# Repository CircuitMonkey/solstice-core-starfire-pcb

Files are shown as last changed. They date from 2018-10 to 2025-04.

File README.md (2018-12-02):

# solstice-core-starfire-pcb
Solstice Design System —  *Starfire* Core —  Eagle PCB

PCB files for the **Circuit Monkey** *StarFire*  **Solstice Core** *Module*

Format is EagleCAD 9.x schematic and board layout

*StarFire* is one of the first *Solstice Core* modules.

For more details, check out the product page at

  * https://www.circuitmonkey.com/product/0701   ( [404 - not found] this link is not yet active)

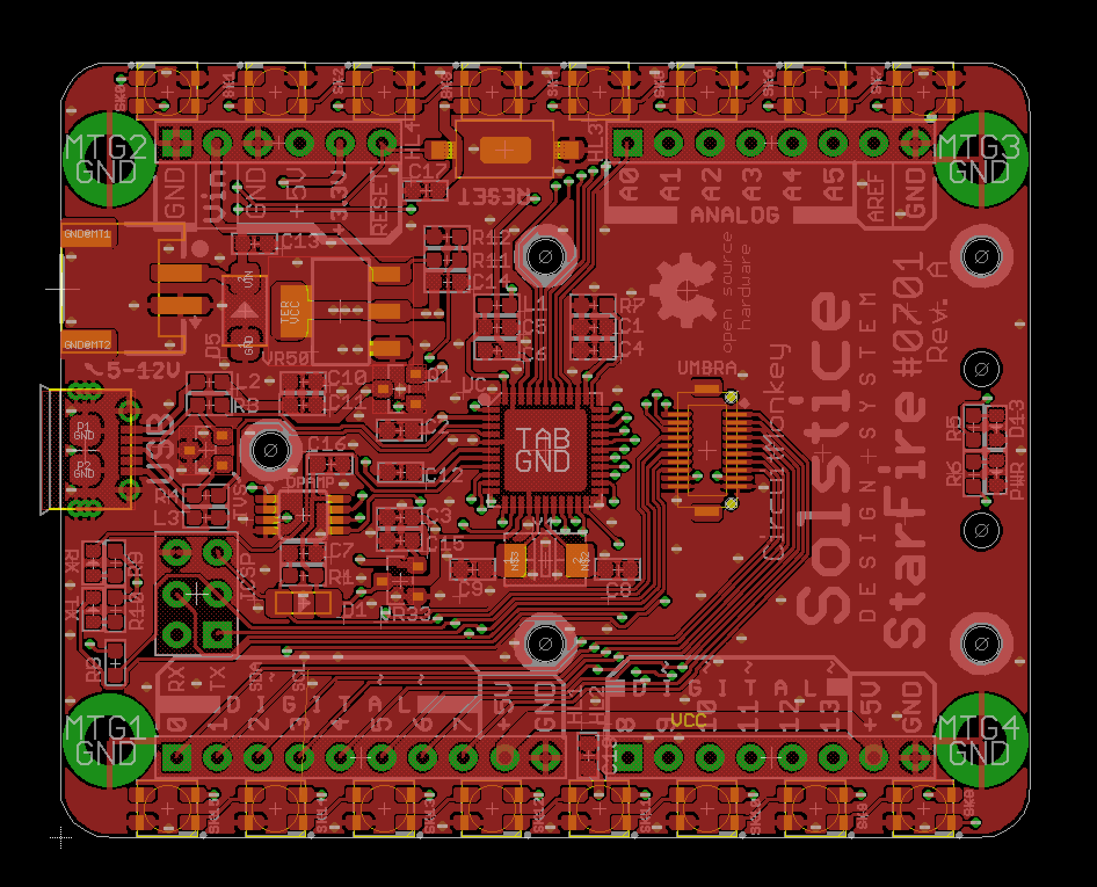
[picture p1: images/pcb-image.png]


### Revision Notes
* Rev. 0 - Initial board design.  This revision was made for evaluation and only
one unit ever made.

* Rev. A - First revision meant for human consumption.
  * Swapped Vin and GND pins on HaLo connector.   Vin was dangerously close to GND mounting hole.
  * Changed WS2812B (5x5mm) LEDs to smaller SK6812(3.5x3.5mm LEDs)
  * SK6812 LED chain is driven by SCK pin.  Was MISO pin on Rev.0 and pattern would scramble when ISP programming the board.
  * Reset switch changed to slightly larger type.
  * Mounting holes on corners changed from 2mm pan head-style to 3mm socket head type.  2mm hardware is harder to source.
  * Added Umbra connector.  A Umbra is 20-pin micro-shield that is approx. 1x1 inch and can mount under the regular shield(HaLo).
  * Added Umbra hardware mounting points throughout PCB.
  * Added mounting holes to support light pipe option at the PWR and D13 LEDs.

* Rev. B - Production version.
  * Added EN_PIXELS solder jumper on bottom of PCB to allow disabling of built-in RGB LEDs.
  * Added test points at bottom of PCB to allow externally extending the 16 on-board LEDs.
  * Added 330ohm serial resistor to external pixel output.
  * USB connector footprint issue addressed.  Footprint was correct, Seeed part number was incorrect.

## Designed by Circuit Monkey in Las Vegas, Nevada, USA
Creative Commons Attribution, Share-Alike license, check license.txt for more information. Derivative of "Arduino Leonardo Reference design" (http://www.arduino.cc/en/Main/ArduinoBoardLeonardo)

All text above must be included in any redistribution

## Gallery
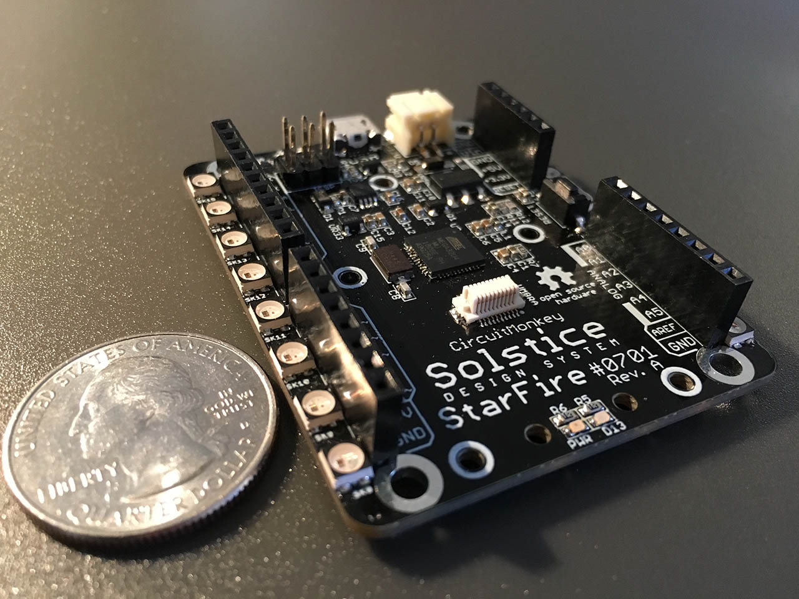
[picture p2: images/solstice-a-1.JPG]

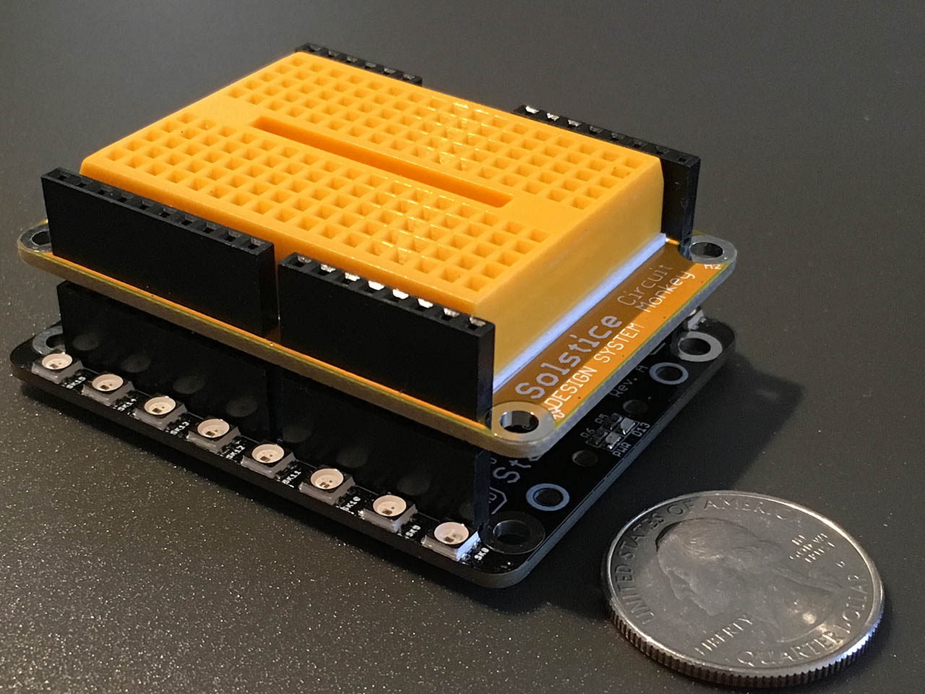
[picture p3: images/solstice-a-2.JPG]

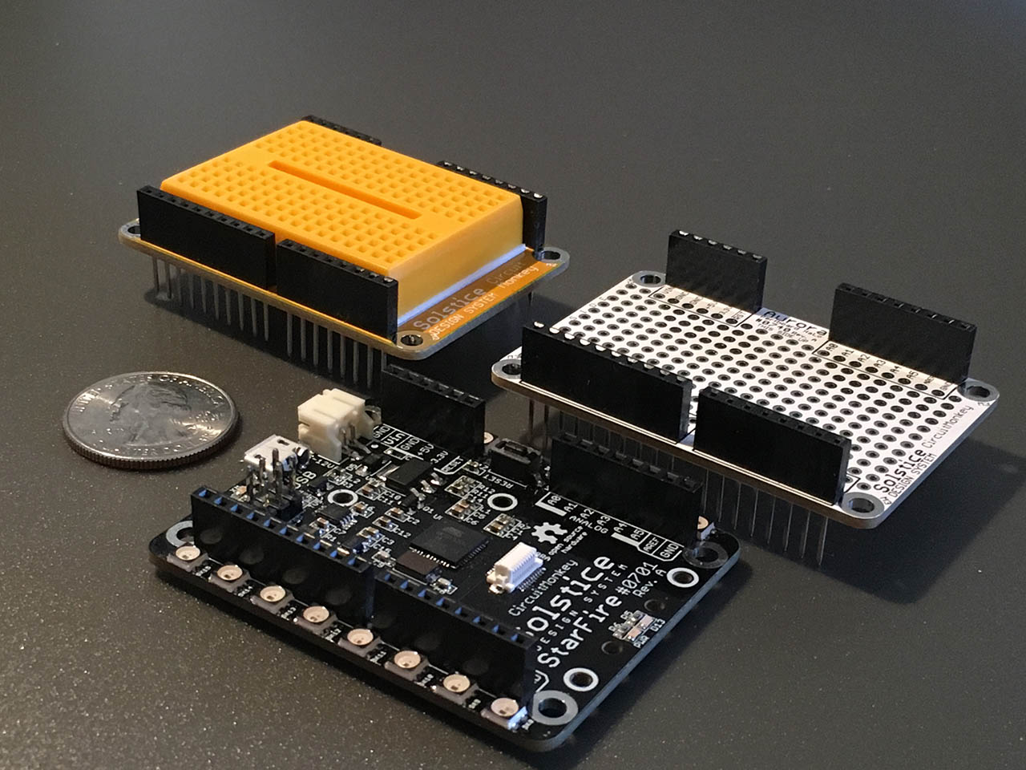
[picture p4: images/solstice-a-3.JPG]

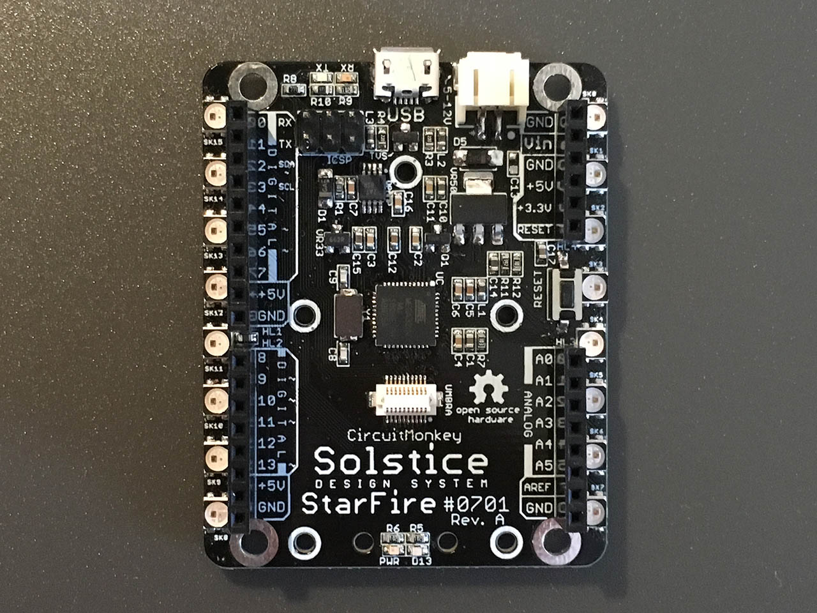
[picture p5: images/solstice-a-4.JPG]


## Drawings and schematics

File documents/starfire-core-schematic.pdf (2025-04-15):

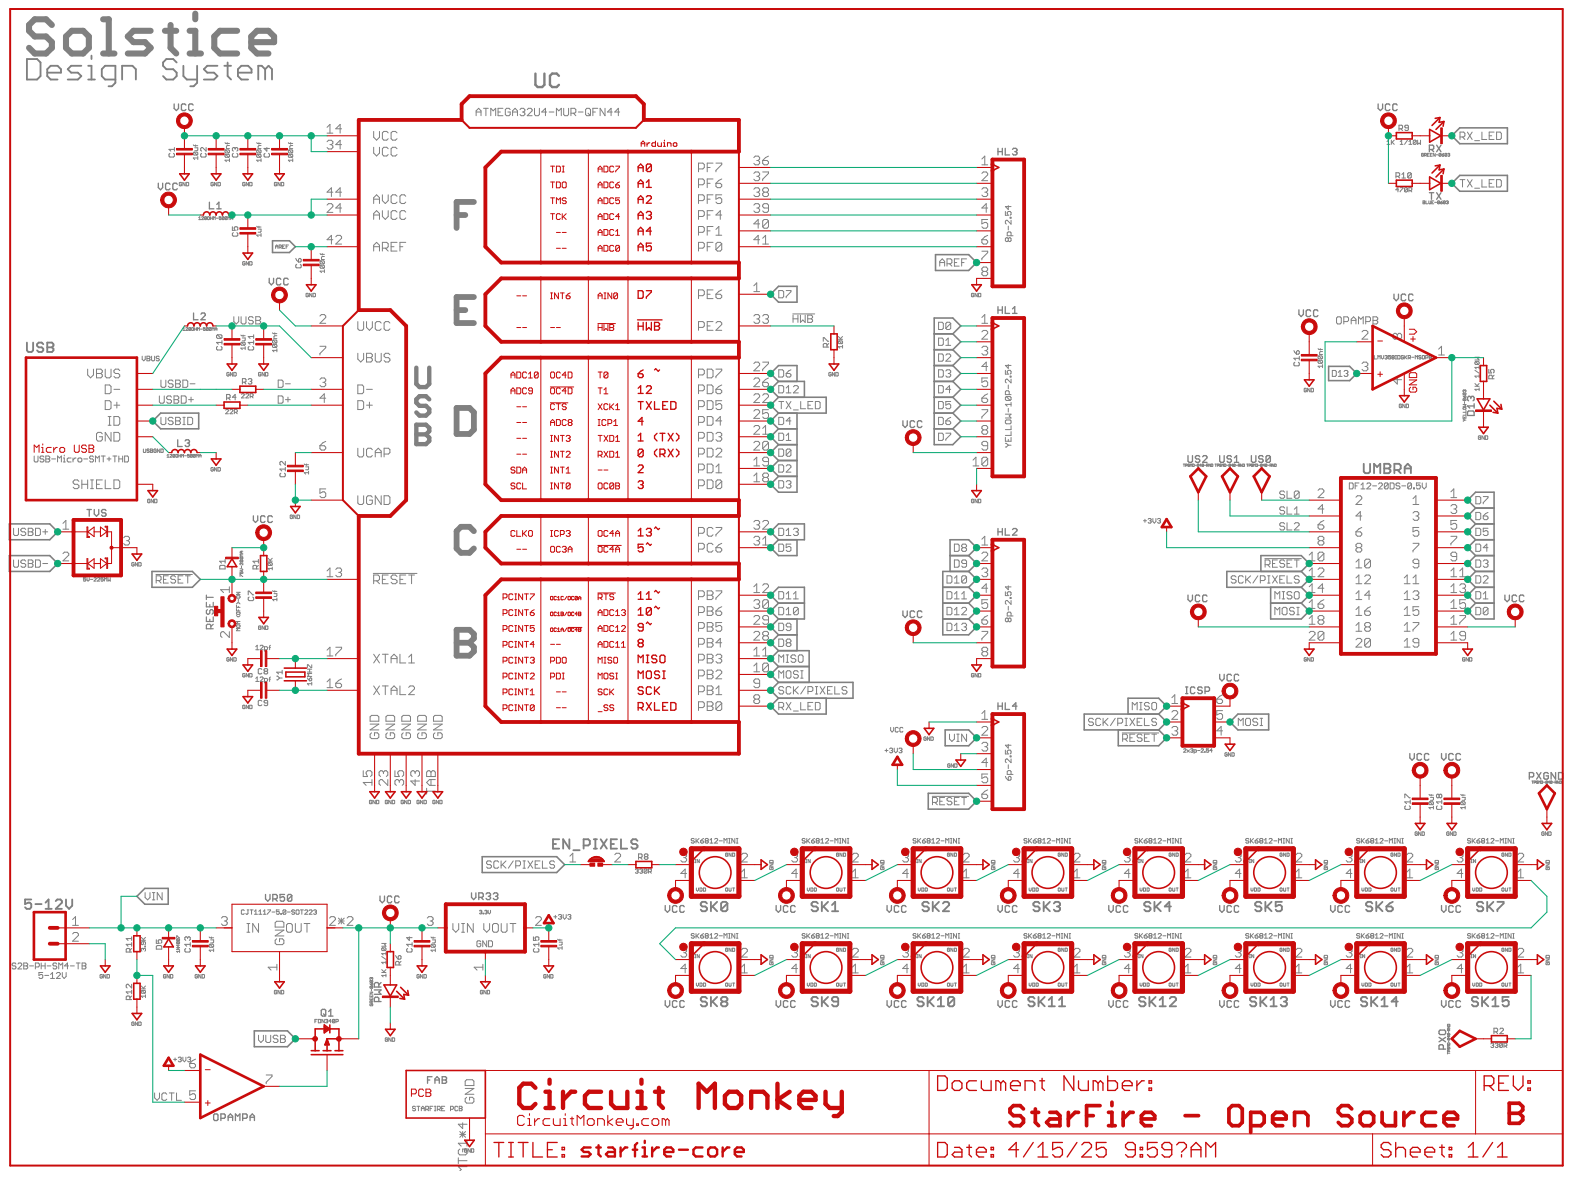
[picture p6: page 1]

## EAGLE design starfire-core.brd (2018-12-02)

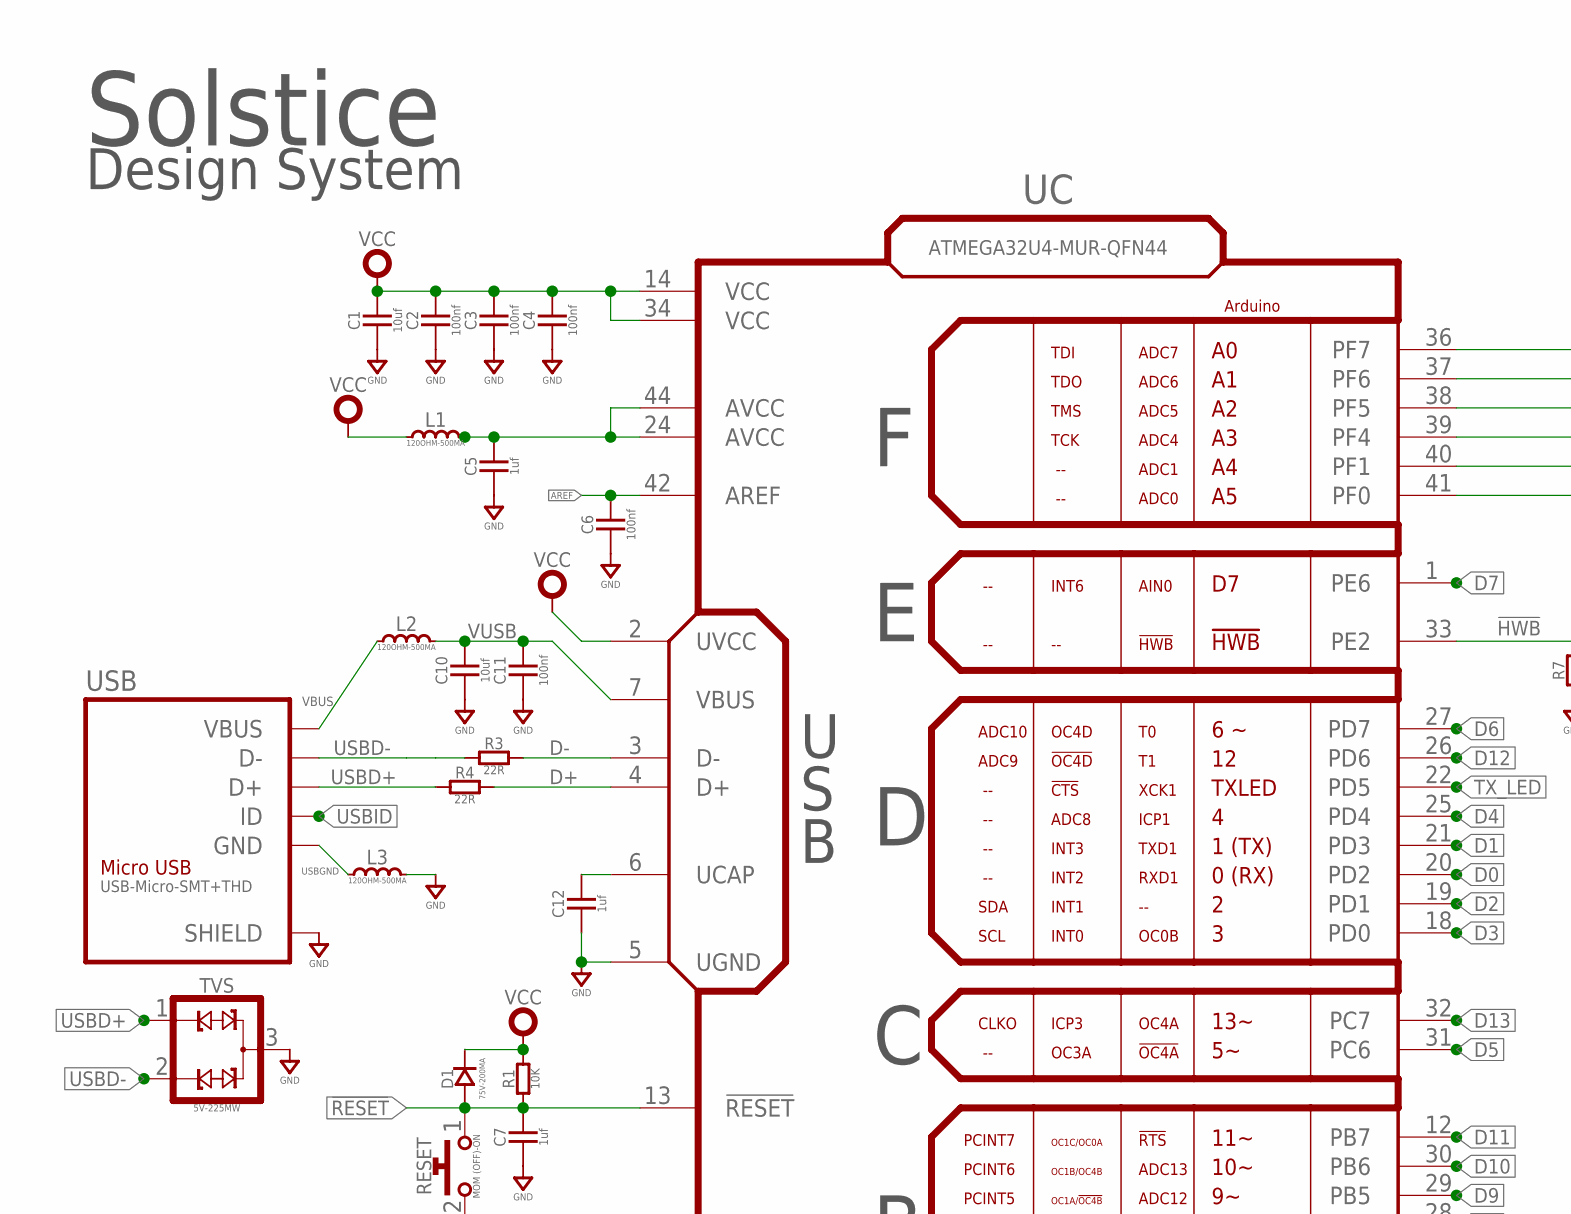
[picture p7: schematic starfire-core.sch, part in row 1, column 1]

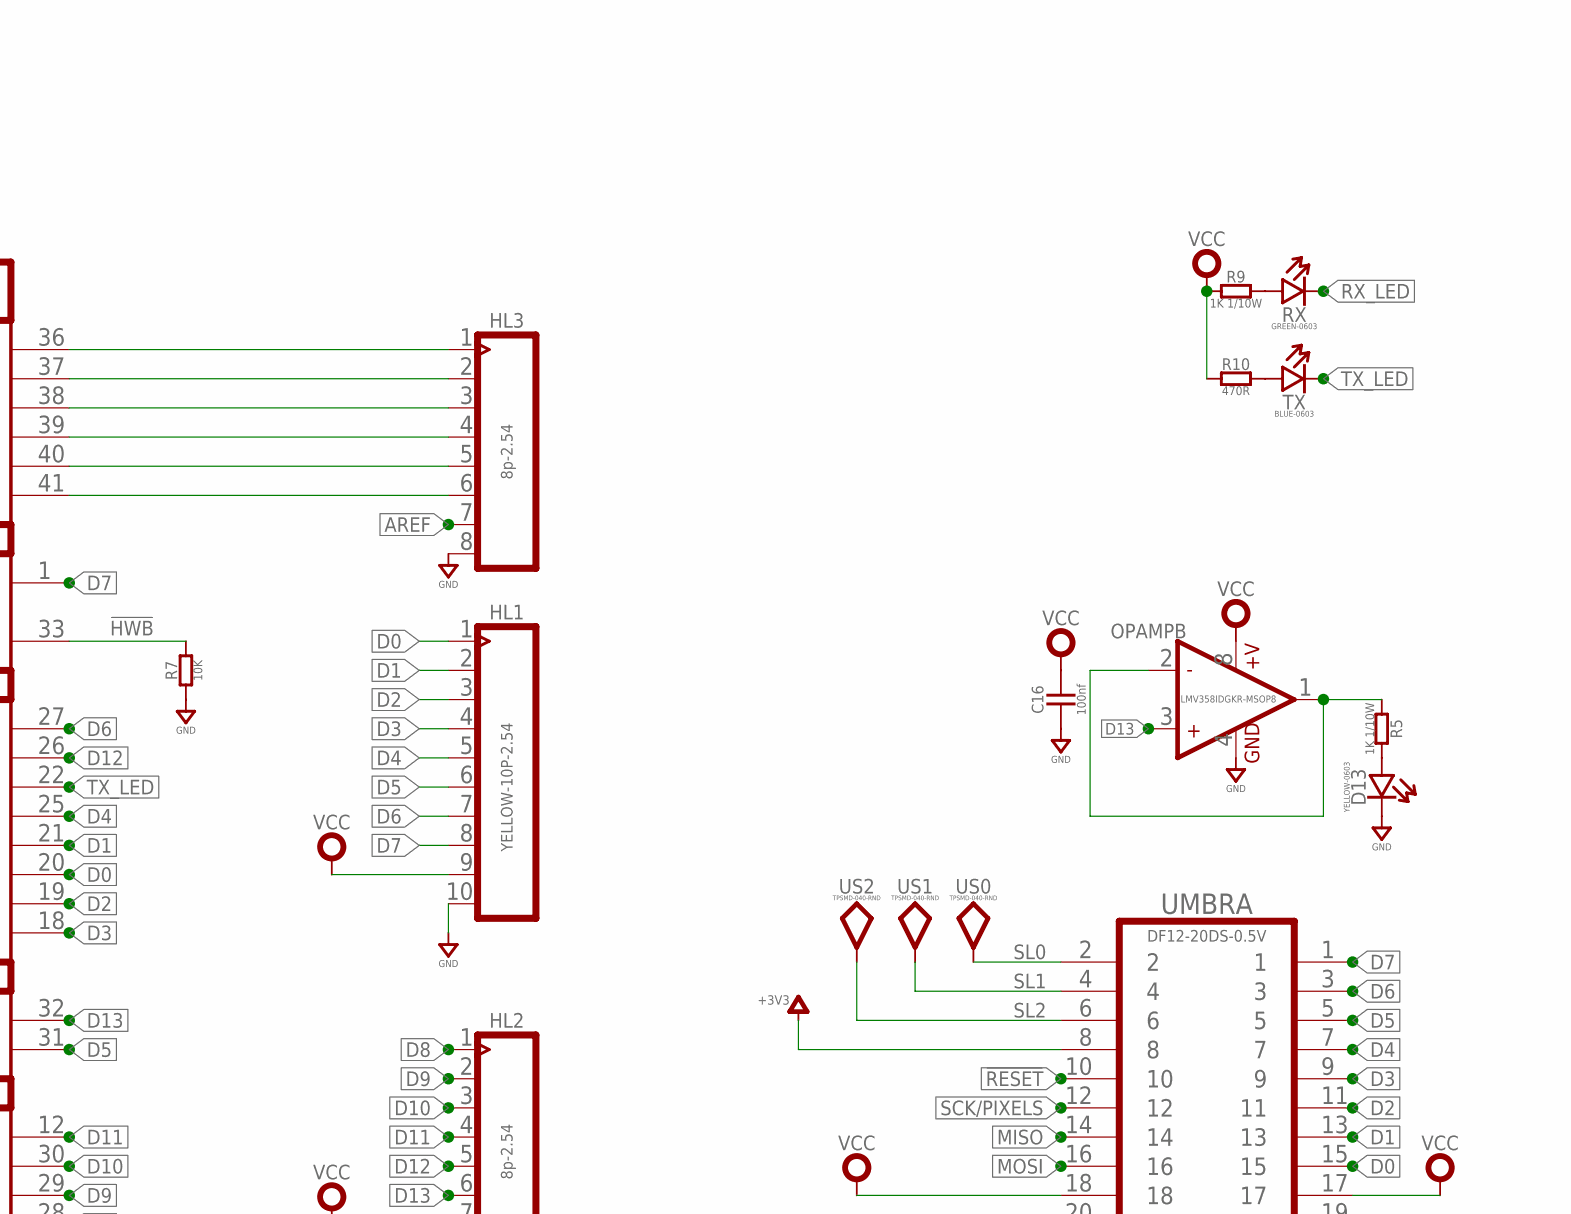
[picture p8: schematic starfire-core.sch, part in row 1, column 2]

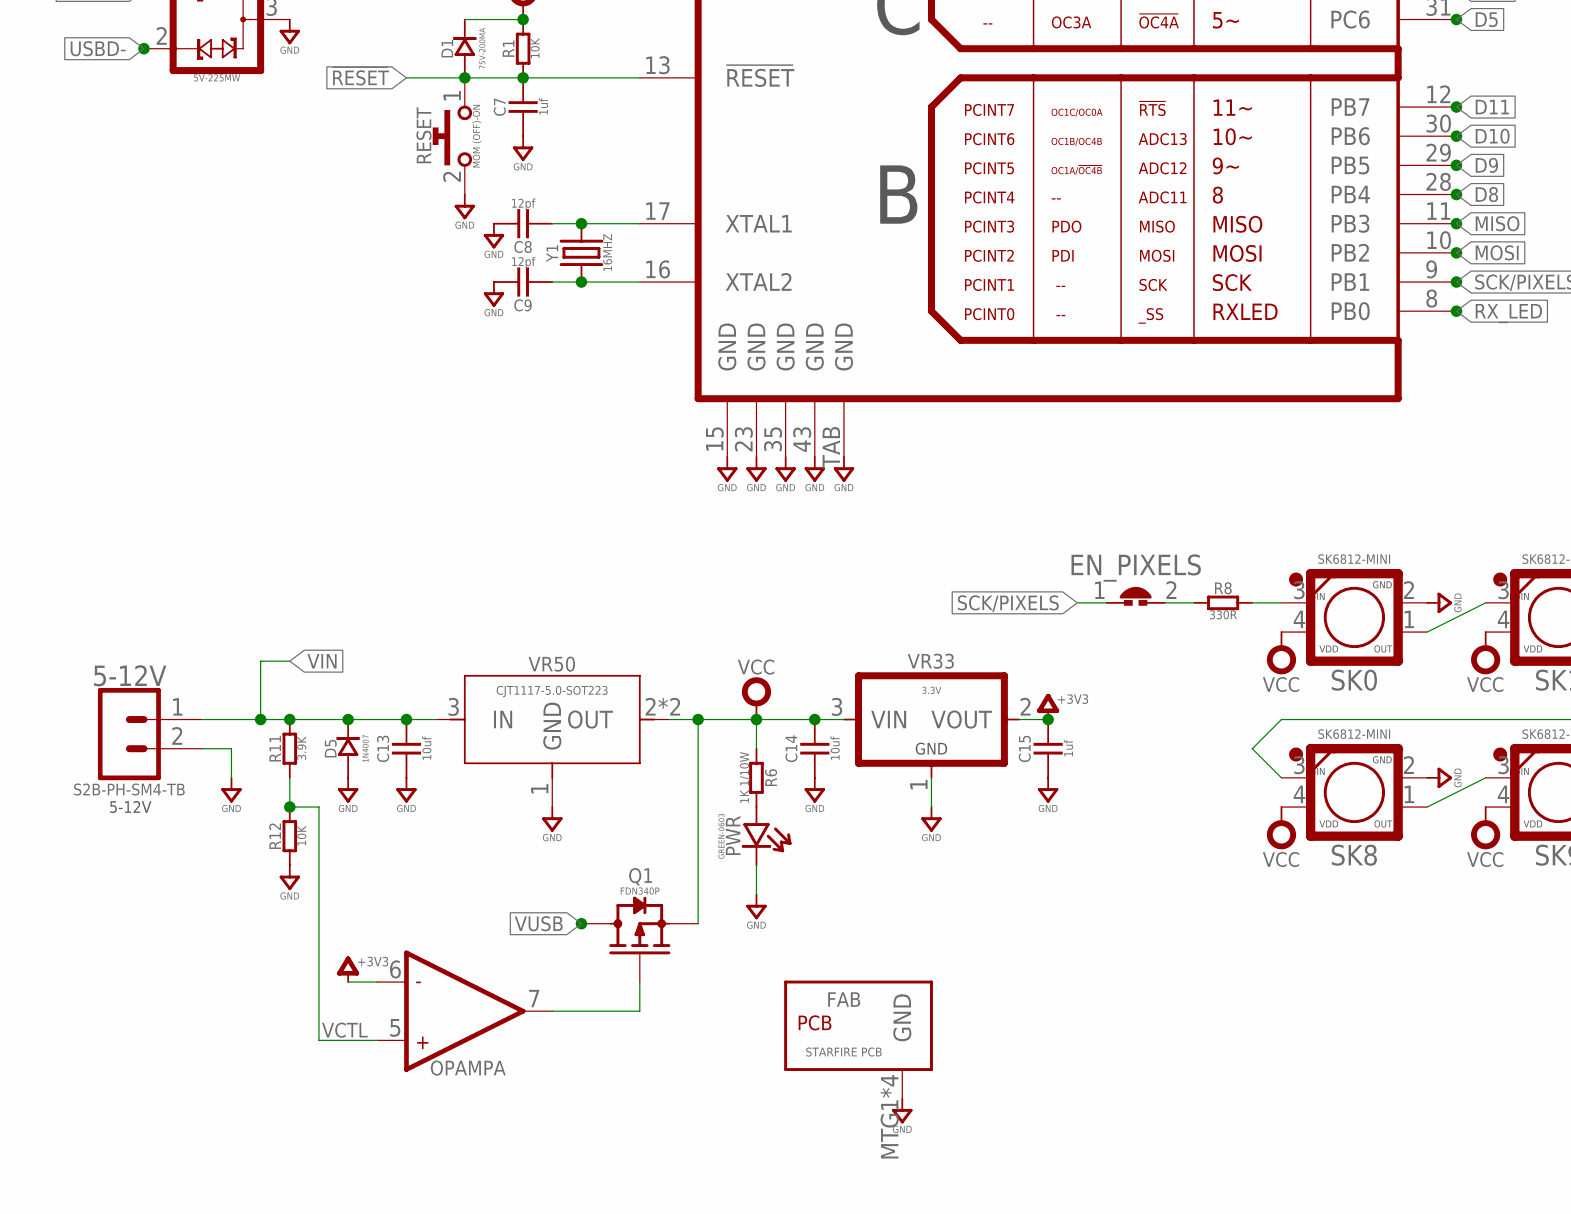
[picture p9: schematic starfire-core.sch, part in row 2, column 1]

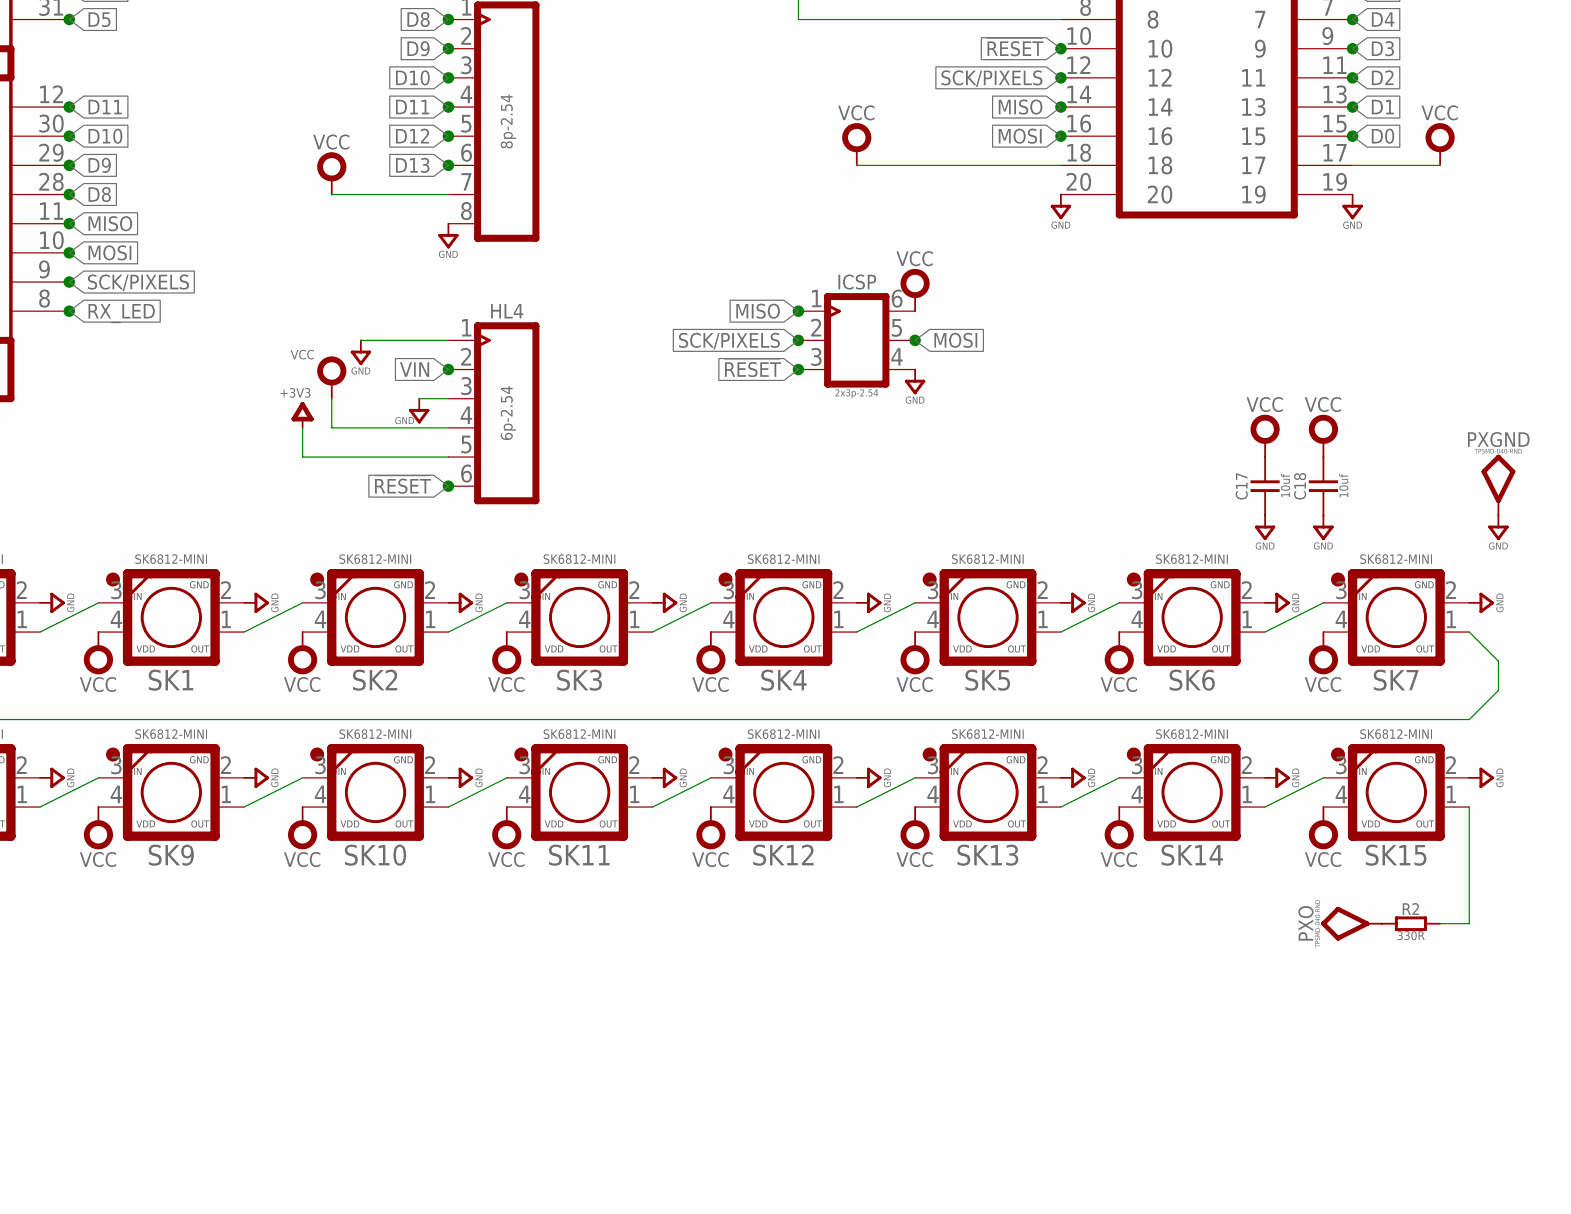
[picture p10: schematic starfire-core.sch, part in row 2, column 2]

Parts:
5-12V: S2B-PH-SM4-TB; S2B-PH-SM4-
C1, C10, C13, C14, C17, C18: 10uf; C0603
C2, C3, C4, C6, C11, C16: 100nf; C0603
C5, C7, C12, C15: 1uf; C0603
C8, C9: 12pf; C0603
D1: 75V-200MA; LL-34
D5: 1N4007; DO-214AC
D13: YELLOW-0603; LED-0603
EN_PIXELS: SOLDER_JUMPER-80MIL-RND; SOLDER_JUMP_80MIL_RND
FAB: STARFIRE PCB; PCB-BASE-B1
HL1: YELLOW-10P-2.54; H10-2.54
HL2, HL3: 8p-2.54; H8-2.54
HL4: 6p-2.54; H6-2.54
ICSP: 2x3p-2.54; H2X3-2.54
L1, L2, L3: 120OHM-500MA; L0603
OPAMP: LMV358IDGKR-MSOP8; MSOP8-0.65-3X3MM
PWR: GREEN-0603; LED-0603
PXGND: TPSMD-040-RND; SMD-040MIL-RND
PXO: TPSMD-040-RND; SMD-040MIL-RND
Q1: FDN340P; SOT-23
R1, R7, R12: 10K; R0603
R2, R8: 330R; R0603
R3, R4: 22R; R0603
R5, R6, R9: 1K 1/10W; R0603
R10: 470R; R0603
R11: 3.9K; R0603
RESET: MOM (OFF)-ON; SWITCH-0635-2P-SMD
RX: GREEN-0603; LED-0603
SK0, SK1, SK2, SK3, SK4, SK5, SK6, SK7, SK8, SK9, SK10, SK11, SK12, SK13, SK14, SK15: SK6812-MINI; SMD_3535
TVS: 5V-225MW; SOT-23
TX: BLUE-0603; LED-0603
UC: ATMEGA32U4-MUR-QFN44; QFN44G-0.5-7X7MM
UMBRA: DF12-20DS-0.5V; DF12-20P-RCPT-MTL-BOSS
US0, US1, US2: TPSMD-040-RND; SMD-040MIL-RND
USB: USB-Micro-SMT+THD; MICRO-USB5+6P-SMD-0.65-AB
VR33: 3.3V; SOT-23
VR50: CJT1117-5.0-SOT223; SOT-223
Y1: 16MHZ; X2-SMD-5.0X3.2X1.3MM

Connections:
!HWB: R7.2, UC.33 (PE2)
!RESET: C7.2, D1.A (+), HL4.6, ICSP.3, R1.1, RESET.1, UC.13 (!RESET), UMBRA.10
+3V3: C15.2, HL4.5, OPAMP.6 (-IN2), UMBRA.8, VR33.2 (VOUT)
AREF: C6.2, HL3.7, UC.42 (AREF)
AVCC: C5.2, L1.2, UC.24 (AVCC), UC.44 (AVCC)
D0: HL1.1, UC.20 (PD2), UMBRA.15
D1: HL1.2, UC.21 (PD3), UMBRA.13
D2: HL1.3, UC.19 (PD1), UMBRA.11
D3: HL1.4, UC.18 (PD0), UMBRA.9
D4: HL1.5, UC.25 (PD4), UMBRA.7
D5: HL1.6, UC.31 (PC6), UMBRA.5
D6: HL1.7, UC.27 (PD7), UMBRA.3
D7: HL1.8, UC.1 (PE6), UMBRA.1
D8: HL2.1, UC.28 (PB4)
D9: HL2.2, UC.29 (PB5)
D10: HL2.3, UC.30 (PB6)
D11: HL2.4, UC.12 (PB7)
D12: HL2.5, UC.26 (PD6)
D13: HL2.6, OPAMP.3 (+IN1), UC.32 (PC7)
D+: R4.2, UC.4 (D+)
D-: R3.2, UC.3 (D-)
GND: 5-12V.2, C1.1, C2.1, C3.1, C4.1, C5.1, C6.1, C7.1, C8.2, C9.2, C10.1, C11.1, C12.1, C13.1, C14.1, C15.1, C16.1, C17.1, C18.1, D5.1 (+), D13.-, FAB.MTG1, FAB.MTG2, FAB.MTG3, FAB.MTG4, HL1.10, HL2.8, HL3.8, HL4.1, HL4.3, ICSP.4, L3.2, OPAMP.4 (GND), PWR.-, PXGND.TP, R7.1, R12.1, RESET.2, SK0.2 (GND), SK1.2 (GND), SK2.2 (GND), SK3.2 (GND), SK4.2 (GND), SK5.2 (GND), SK6.2 (GND), SK7.2 (GND), SK8.2 (GND), SK9.2 (GND), SK10.2 (GND), SK11.2 (GND), SK12.2 (GND), SK13.2 (GND), SK14.2 (GND), SK15.2 (GND), TVS.3, UC.5 (UGND), UC.15 (GND), UC.23 (GND), UC.35 (GND), UC.43 (GND), UC.TAB (GND), UMBRA.19, UMBRA.20, USB.P1 (SHIELD), USB.P2 (SHIELD), USB.P3_1 (SHIELD), USB.P3_2 (SHIELD), USB.P3_3 (SHIELD), USB.P4_1 (SHIELD), USB.P4_2 (SHIELD), USB.P4_3 (SHIELD), USB.P5 (SHIELD), USB.P6 (SHIELD), VR33.1 (VSS), VR50.1 (GND)
MISO: ICSP.1, UC.11 (PB3), UMBRA.14
MOSI: ICSP.5, UC.10 (PB2), UMBRA.16
unnamed: SK0.1 (OUT), SK1.3 (IN)
unnamed: C8.1, UC.17 (XTAL1), Y1.2
unnamed: C9.1, UC.16 (XTAL2), Y1.1
unnamed: SK1.1 (OUT), SK2.3 (IN)
unnamed: SK2.1 (OUT), SK3.3 (IN)
unnamed: SK3.1 (OUT), SK4.3 (IN)
unnamed: HL3.1, UC.36 (PF7)
unnamed: D13.+, R5.2
unnamed: SK4.1 (OUT), SK5.3 (IN)
unnamed: PWR.+, R6.2
unnamed: SK5.1 (OUT), SK6.3 (IN)
unnamed: SK6.1 (OUT), SK7.3 (IN)
unnamed: SK8.1 (OUT), SK9.3 (IN)
unnamed: R8.2, SK0.3 (IN)
unnamed: SK9.1 (OUT), SK10.3 (IN)
unnamed: SK10.1 (OUT), SK11.3 (IN)
unnamed: SK11.1 (OUT), SK12.3 (IN)
unnamed: SK12.1 (OUT), SK13.3 (IN)
unnamed: SK13.1 (OUT), SK14.3 (IN)
unnamed: SK14.1 (OUT), SK15.3 (IN)
unnamed: R10.2, TX.+
unnamed: R9.2, RX.+
unnamed: HL3.2, UC.37 (PF6)
unnamed: HL3.3, UC.38 (PF5)
unnamed: HL3.4, UC.39 (PF4)
unnamed: HL3.5, UC.40 (PF1)
unnamed: HL3.6, UC.41 (PF0)
unnamed: SK7.1 (OUT), SK8.3 (IN)
unnamed: PXO.TP, R2.1
unnamed: R2.2, SK15.1 (OUT)
unnamed: OPAMP.1 (OUT1), OPAMP.2 (-IN1), R5.1
unnamed: OPAMP.7 (OUT2), Q1.1 (G)
PIXELS: EN_PIXELS.2, R8.1
RX_LED: RX.-, UC.8 (PB0)
SCK/PIXELS: EN_PIXELS.1, ICSP.2, UC.9 (PB1), UMBRA.12
SL0: UMBRA.2, US0.TP
SL1: UMBRA.4, US1.TP
SL2: UMBRA.6, US2.TP
TX_LED: TX.-, UC.22 (PD5)
UCAP: C12.2, UC.6 (UCAP)
USBD+: R4.1, TVS.1, USB.3 (D+)
USBD-: R3.1, TVS.2, USB.2 (D-)
USBGND: L3.1, USB.5 (GND)
USBID: USB.4 (ID)
VBUS: L2.1, USB.1 (VBUS)
VCC: C1.2, C2.2, C3.2, C4.2, C14.2, C16.2, C17.2, C18.2, D1.C (-), HL1.9, HL2.7, HL4.4, ICSP.6, L1.1, OPAMP.8 (+V), Q1.2 (S), R1.2, R6.1, R9.1, R10.1, SK0.4 (VDD), SK1.4 (VDD), SK2.4 (VDD), SK3.4 (VDD), SK4.4 (VDD), SK5.4 (VDD), SK6.4 (VDD), SK7.4 (VDD), SK8.4 (VDD), SK9.4 (VDD), SK10.4 (VDD), SK11.4 (VDD), SK12.4 (VDD), SK13.4 (VDD), SK14.4 (VDD), SK15.4 (VDD), UC.2 (UVCC), UC.14 (VCC), UC.34 (VCC), UMBRA.17, UMBRA.18, VR33.3 (VIN), VR50.2 (OUT), VR50.TER (OUT)
VCTL: OPAMP.5 (+IN2), R11.1, R12.2
VIN: 5-12V.1, C13.2, D5.2 (-), HL4.2, R11.2, VR50.3 (IN)
VUSB: C10.2, C11.2, L2.2, Q1.3 (D), UC.7 (VBUS)

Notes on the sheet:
Solstice
5-12V
Design System

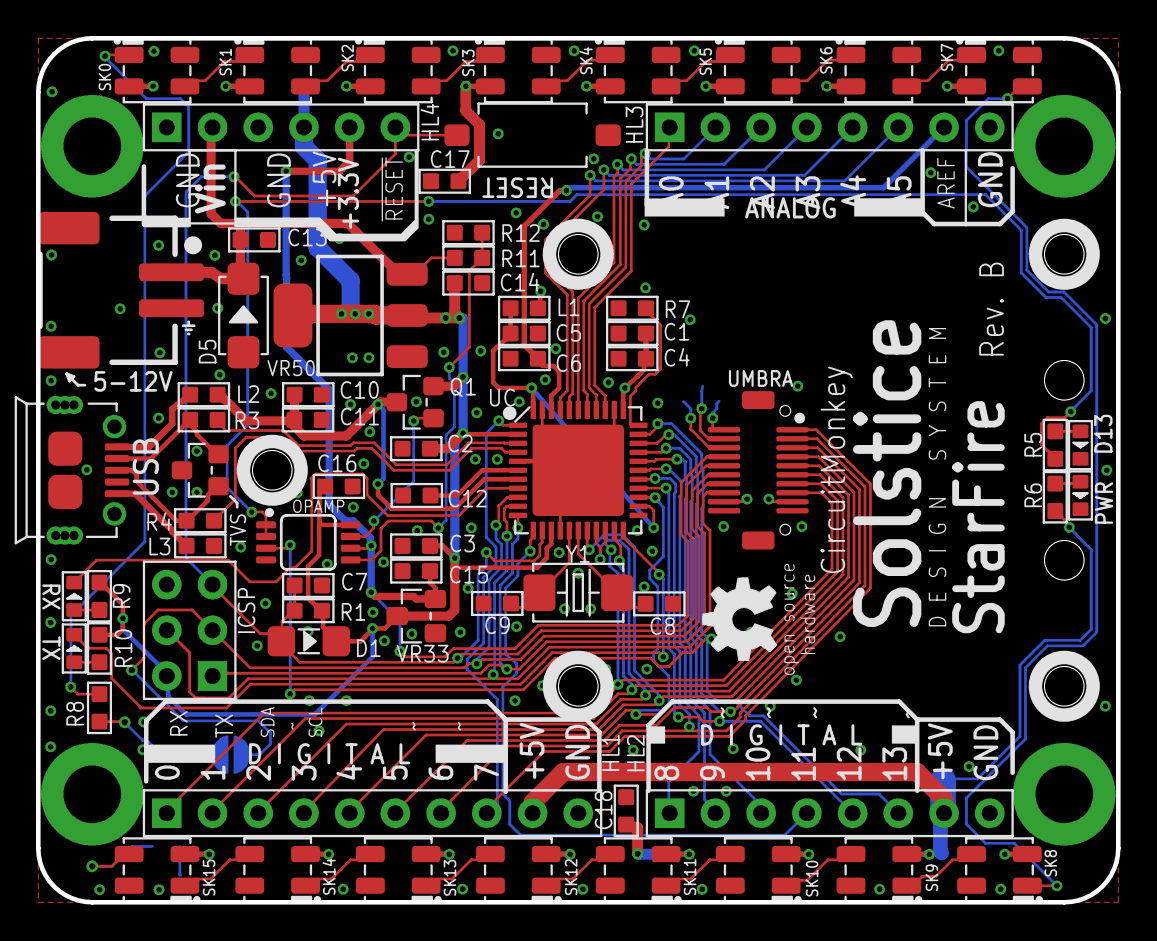
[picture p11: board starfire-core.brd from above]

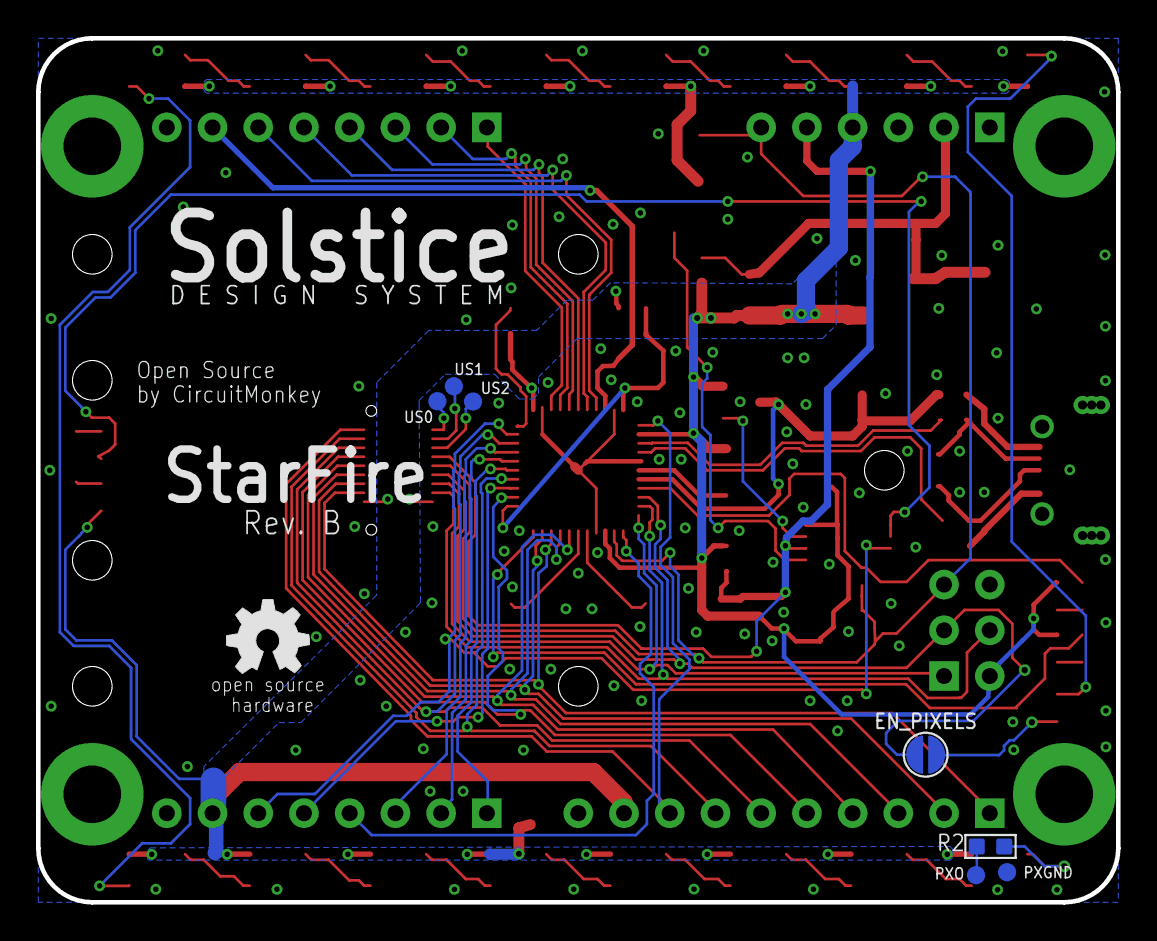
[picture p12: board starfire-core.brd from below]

Board: 2 copper layers, 60.0 x 48.0 mm, 80 parts (8 on the bottom side), 72 nets.

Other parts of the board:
U$2, U$3: OSHW_5MM

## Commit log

2018-05-20 Upload pre-release board proto BRD and SCH.
    [starfire-core.brd, starfire-core.sch]
2018-06-10 starfire eaglecad lbr refernce moved.
    I renamed and moved the EagleCAD library for the PCB fab compoment to our public git repo. So updated the BRD and SCH references so that users can find the correct library.
    [starfire-core.brd, starfire-core.sch]
2018-10-30 Rev. A PCBs shared to world
    [starfire-core.brd, starfire-core.sch]
2018-10-30 CAD Image of PCB added
2018-12-02 Revision B released
    Added Umbra connector feature along with Umbra mount support holes. RGB LEDs are now smaller SK6812 type 3.5x3.5mm. Added output test points for external LED chain that extends on-board chain. Added 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
    [starfire-core.brd, starfire-core.sch]
2025-04-15 Added schematic PDF.
